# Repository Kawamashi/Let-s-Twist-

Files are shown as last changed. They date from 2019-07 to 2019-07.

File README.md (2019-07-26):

# Let's Twist !
## Ergonomic split mechanical keyboard

I'm an [Ergodox keyboard](https://www.ergodox.io/) user. Even if I'm really happy with it, there's room for improvement. *Let's Twist !* is an attempt to gather every brilliant idea I've seen on other ergonomic split keyboards.

First of all, I want to keep some of the Ergodox features :
- the thumb clusters, because it's a great way to lighten the work of the other fingers.
- the columnar staggered arrangement of the keys, because it's way more natural than the traditional row staggered layout.
- the split design, because it allows you to have a very comfortable position.
- programmable with QMK, I don't think I need to explain why…
- 1.5u wide keys on the outer columns, because it's aesthetically pleasing ! 
- wired connectivity, because I don't like to rely on batteries, and because I like my custom cables !

Then, like a lot of people, I find that the thumb clusters of the Ergodox are too far away from the alphas. I saw Mikel Duffy's great [modified Ergodox](https://medium.com/@mikelduffy/hand-wiring-a-modified-ergodox-1adbfc479468), and I want the two main thumb keys to be in the same position.

My project was heavily inspired by Mattia Dal Ben's [Redox keyboard](https://github.com/mattdibi/redox-keyboard). It's really a stunning project. Like him, I want my keyboard to have a reduced size, and to be able to plug either half (or just one of them) to the PC. 

So, here is the layout I get :

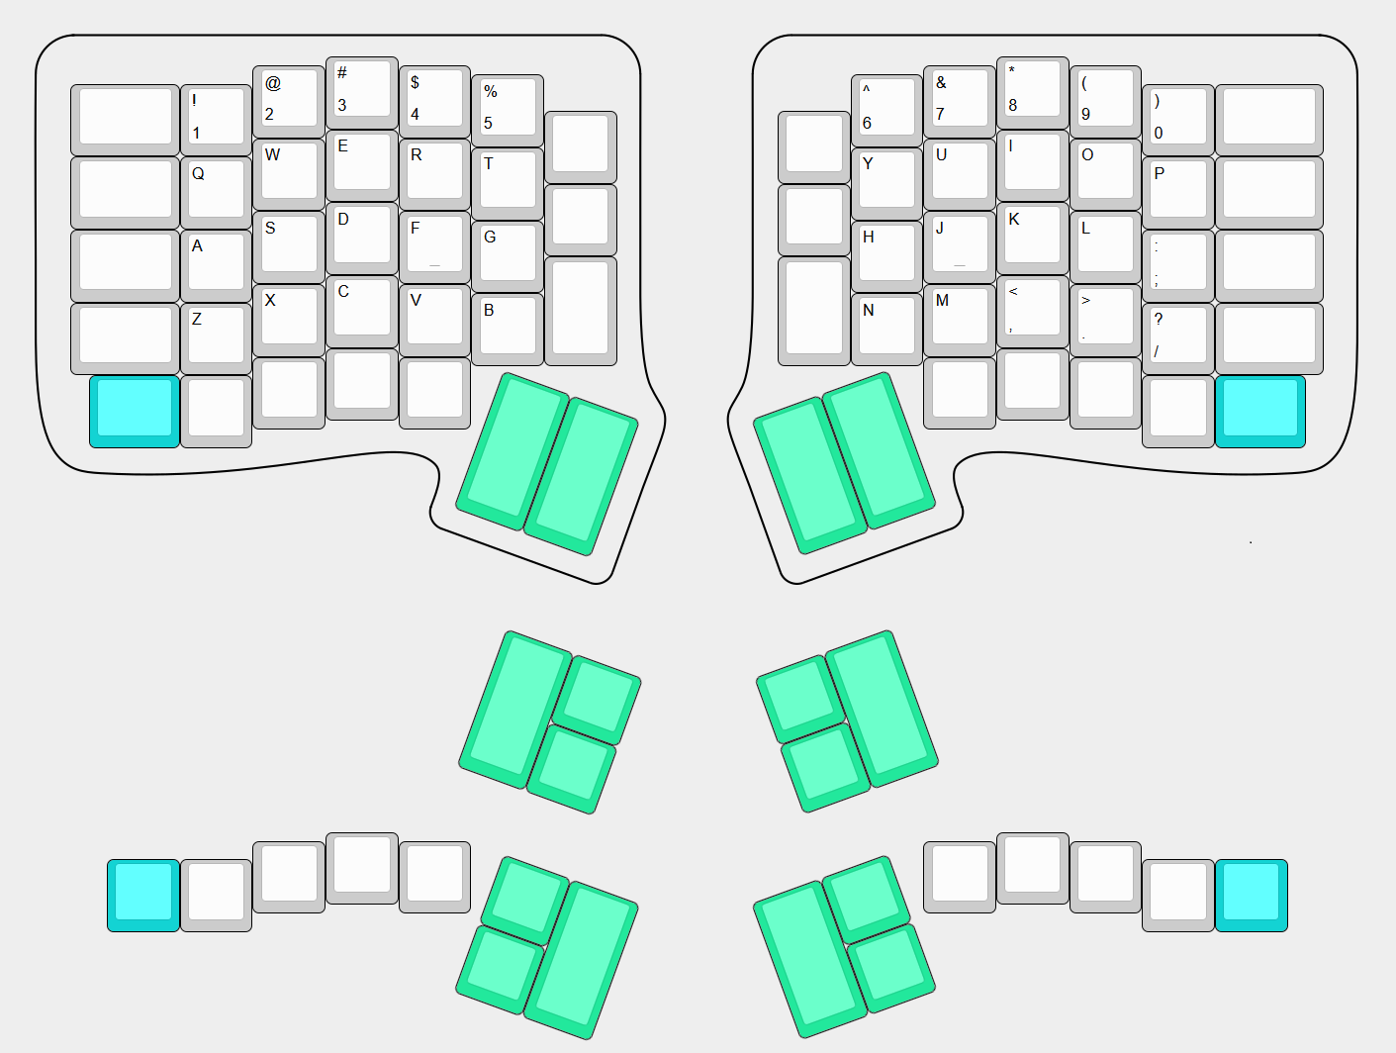
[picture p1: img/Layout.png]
Layout


The PCB can manage 2 or 3 keys for each of the thumb clusters. The blue keys can be 1u or 1.25u.

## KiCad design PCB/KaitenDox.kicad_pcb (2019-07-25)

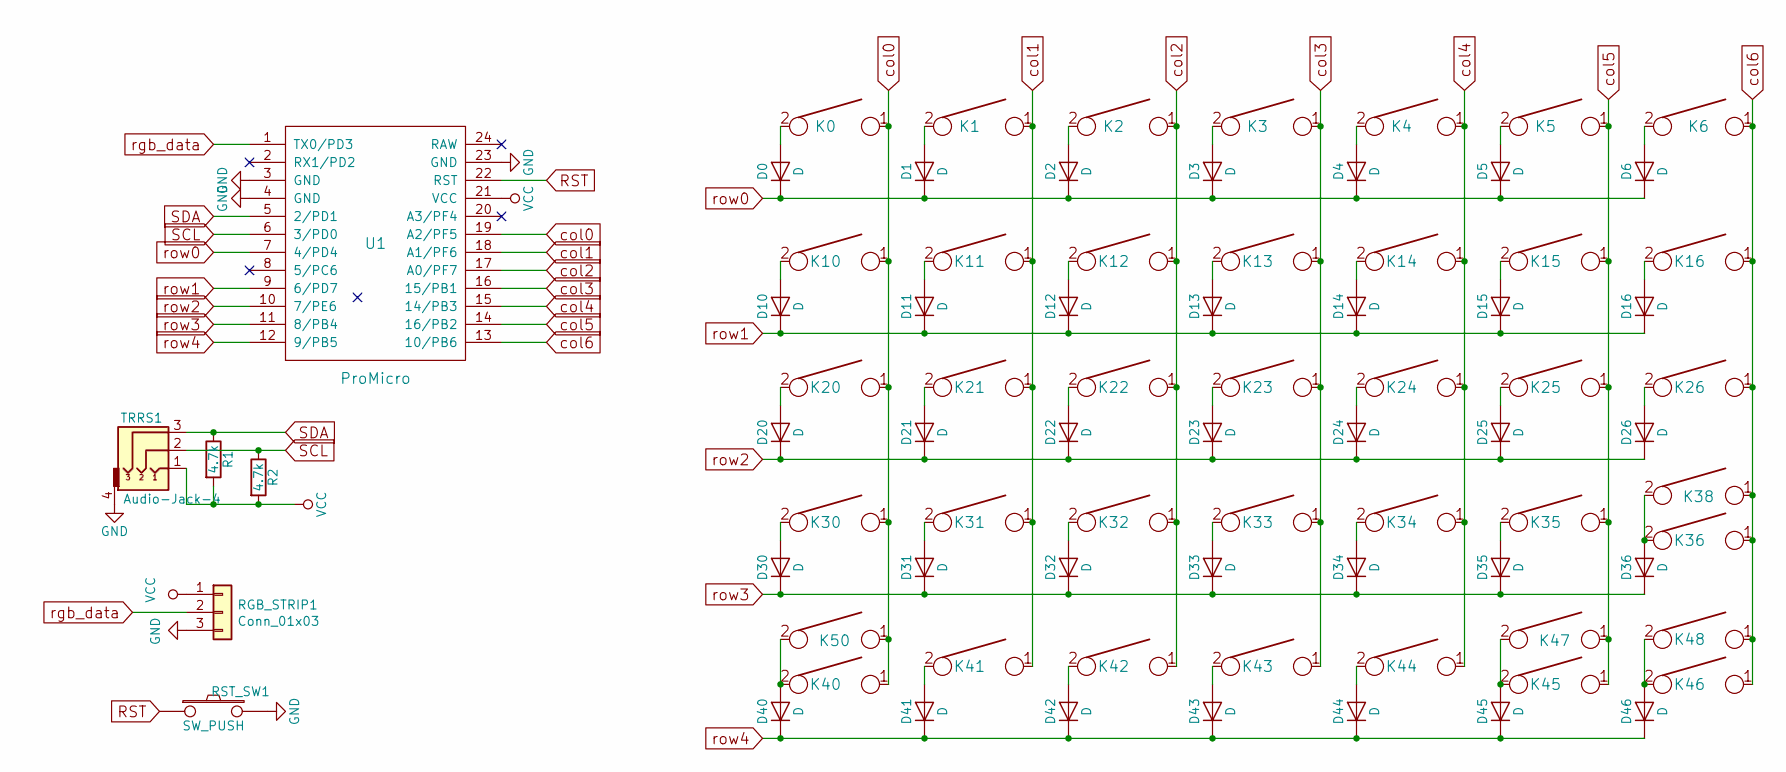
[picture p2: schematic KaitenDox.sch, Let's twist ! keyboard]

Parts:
D0, D1, D2, D3, D4, D5, D6, D10, D11, D12, D13, D14, D15, D16, D20, D21, D22, D23, D24, D25, D26, D30, D31, D32, D33, D34, D35, D36, D40, D41, D42, D43, D44, D45, D46: D; Diode-dual
K0, K10, K20, K26, K30: KEYSW; Mx_Alps_150-dualsided
K1, K2, K3, K4, K5, K6, K11, K12, K13, K14, K15, K16, K21, K22, K23, K24, K25, K31, K32, K33, K34, K35, K36, K38, K41, K42, K43, K44, K45, K46, K47, K48, K50: KEYSW; Mx_Alps_100-dualside
K40: KEYSW; Mx_Alps_125-dualside
R1, R2: 4.7k; Resistor-Compact
RGB_STRIP1: Conn_01x03; Pin_Header_Straight_1x03_Pitch2.54mm
RST_SW1: SW_PUSH; SW_PUSH_6mm_h4.3mm
TRRS1: Audio-Jack-4; TRRS-PJ-320A-dual
U1: ProMicro; ArduinoProMicro

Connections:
GND: RGB_STRIP1.3, RST_SW1.2, TRRS1.4, U1.3 (GND), U1.4 (GND), U1.23 (GND)
unnamed: D0.2 (A), K0.2
unnamed: D1.2 (A), K1.2
unnamed: D2.2 (A), K2.2
unnamed: D3.2 (A), K3.2
unnamed: D4.2 (A), K4.2
unnamed: D5.2 (A), K5.2
unnamed: D6.2 (A), K6.2
unnamed: D10.2 (A), K10.2
unnamed: D11.2 (A), K11.2
unnamed: D12.2 (A), K12.2
unnamed: D13.2 (A), K13.2
unnamed: D14.2 (A), K14.2
unnamed: D15.2 (A), K15.2
unnamed: D16.2 (A), K16.2
unnamed: D20.2 (A), K20.2
unnamed: D21.2 (A), K21.2
unnamed: D22.2 (A), K22.2
unnamed: D23.2 (A), K23.2
unnamed: D24.2 (A), K24.2
unnamed: D25.2 (A), K25.2
unnamed: D26.2 (A), K26.2
unnamed: D30.2 (A), K30.2
unnamed: D31.2 (A), K31.2
unnamed: D32.2 (A), K32.2
unnamed: D33.2 (A), K33.2
unnamed: D34.2 (A), K34.2
unnamed: D35.2 (A), K35.2
unnamed: D36.2 (A), K36.2, K38.2
unnamed: D40.2 (A), K40.2, K50.2
unnamed: D41.2 (A), K41.2
unnamed: D42.2 (A), K42.2
unnamed: D43.2 (A), K43.2
unnamed: D44.2 (A), K44.2
unnamed: D45.2 (A), K45.2, K47.2
unnamed: D46.2 (A), K46.2, K48.2
RST: RST_SW1.1, U1.22 (RST)
SCL: R2.1, TRRS1.2, U1.6 (3/PD0)
SDA: R1.1, TRRS1.3, U1.5 (2/PD1)
VCC: R1.2, R2.2, RGB_STRIP1.1, TRRS1.1, U1.21 (VCC)
col0: K0.1, K10.1, K20.1, K30.1, K40.1, K50.1, U1.19 (A2/PF5)
col1: K1.1, K11.1, K21.1, K31.1, K41.1, U1.18 (A1/PF6)
col2: K2.1, K12.1, K22.1, K32.1, K42.1, U1.17 (A0/PF7)
col3: K3.1, K13.1, K23.1, K33.1, K43.1, U1.16 (15/PB1)
col4: K4.1, K14.1, K24.1, K34.1, K44.1, U1.15 (14/PB3)
col5: K5.1, K15.1, K25.1, K35.1, K45.1, K47.1, U1.14 (16/PB2)
col6: K6.1, K16.1, K26.1, K36.1, K38.1, K46.1, K48.1, U1.13 (10/PB6)
rgb_data: RGB_STRIP1.2, U1.1 (TX0/PD3)
row0: D0.1 (K), D1.1 (K), D2.1 (K), D3.1 (K), D4.1 (K), D5.1 (K), D6.1 (K), U1.7 (4/PD4)
row1: D10.1 (K), D11.1 (K), D12.1 (K), D13.1 (K), D14.1 (K), D15.1 (K), D16.1 (K), U1.9 (6/PD7)
row2: D20.1 (K), D21.1 (K), D22.1 (K), D23.1 (K), D24.1 (K), D25.1 (K), D26.1 (K), U1.10 (7/PE6)
row3: D30.1 (K), D31.1 (K), D32.1 (K), D33.1 (K), D34.1 (K), D35.1 (K), D36.1 (K), U1.11 (8/PB4)
row4: D40.1 (K), D41.1 (K), D42.1 (K), D43.1 (K), D44.1 (K), D45.1 (K), D46.1 (K), U1.12 (9/PB5)

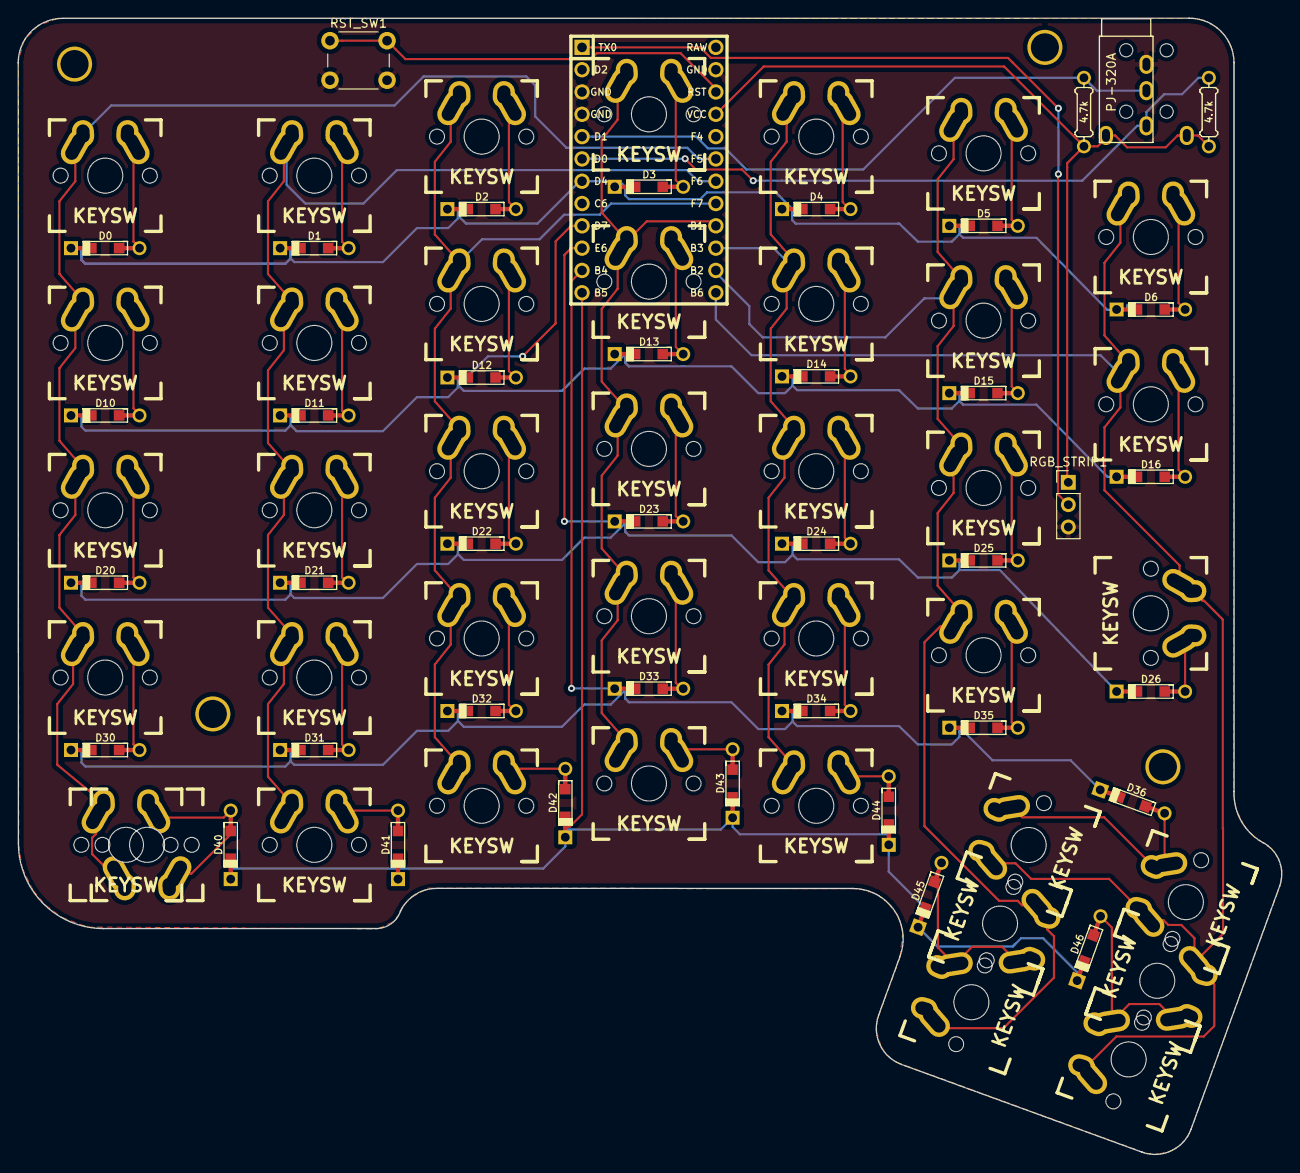
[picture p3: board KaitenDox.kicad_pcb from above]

Board: 2 copper layers, 143.9 x 129.4 mm, 84 parts (1 on the bottom side), 53 nets.

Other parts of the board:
HOLE_M3, HOLE_M3#2, HOLE_M3#3, HOLE_M3#4: VAL**; HOLE_M3
